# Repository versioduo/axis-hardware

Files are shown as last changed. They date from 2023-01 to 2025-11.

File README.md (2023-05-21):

# axis-hardware

🧭 Orientation Sensor Controller

## Board

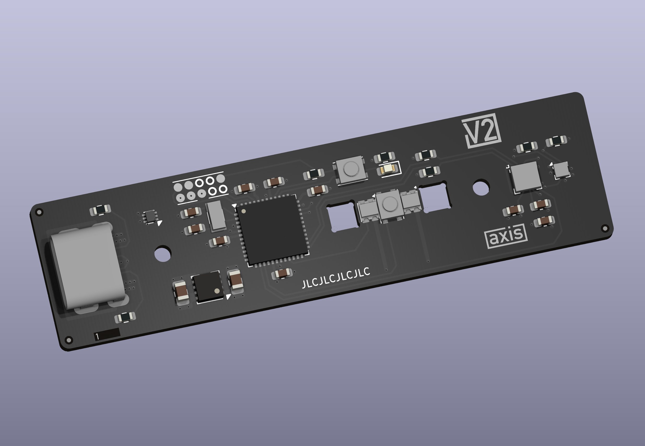
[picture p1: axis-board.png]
board


## Schematic

[PDF](axis.pdf)

## Bill Of Materials

[Interactive BOM](https://htmlpreview.github.io/?https://github.com/versioduo/axis-hardware/main/axis-bom.html)

## Software

Firmware Repository

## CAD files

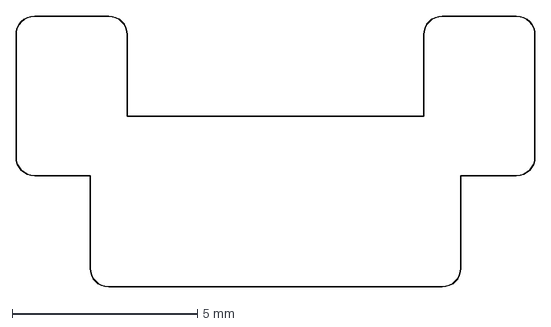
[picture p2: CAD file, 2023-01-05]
button-laser.dxf
14.0 x 7.30 mm

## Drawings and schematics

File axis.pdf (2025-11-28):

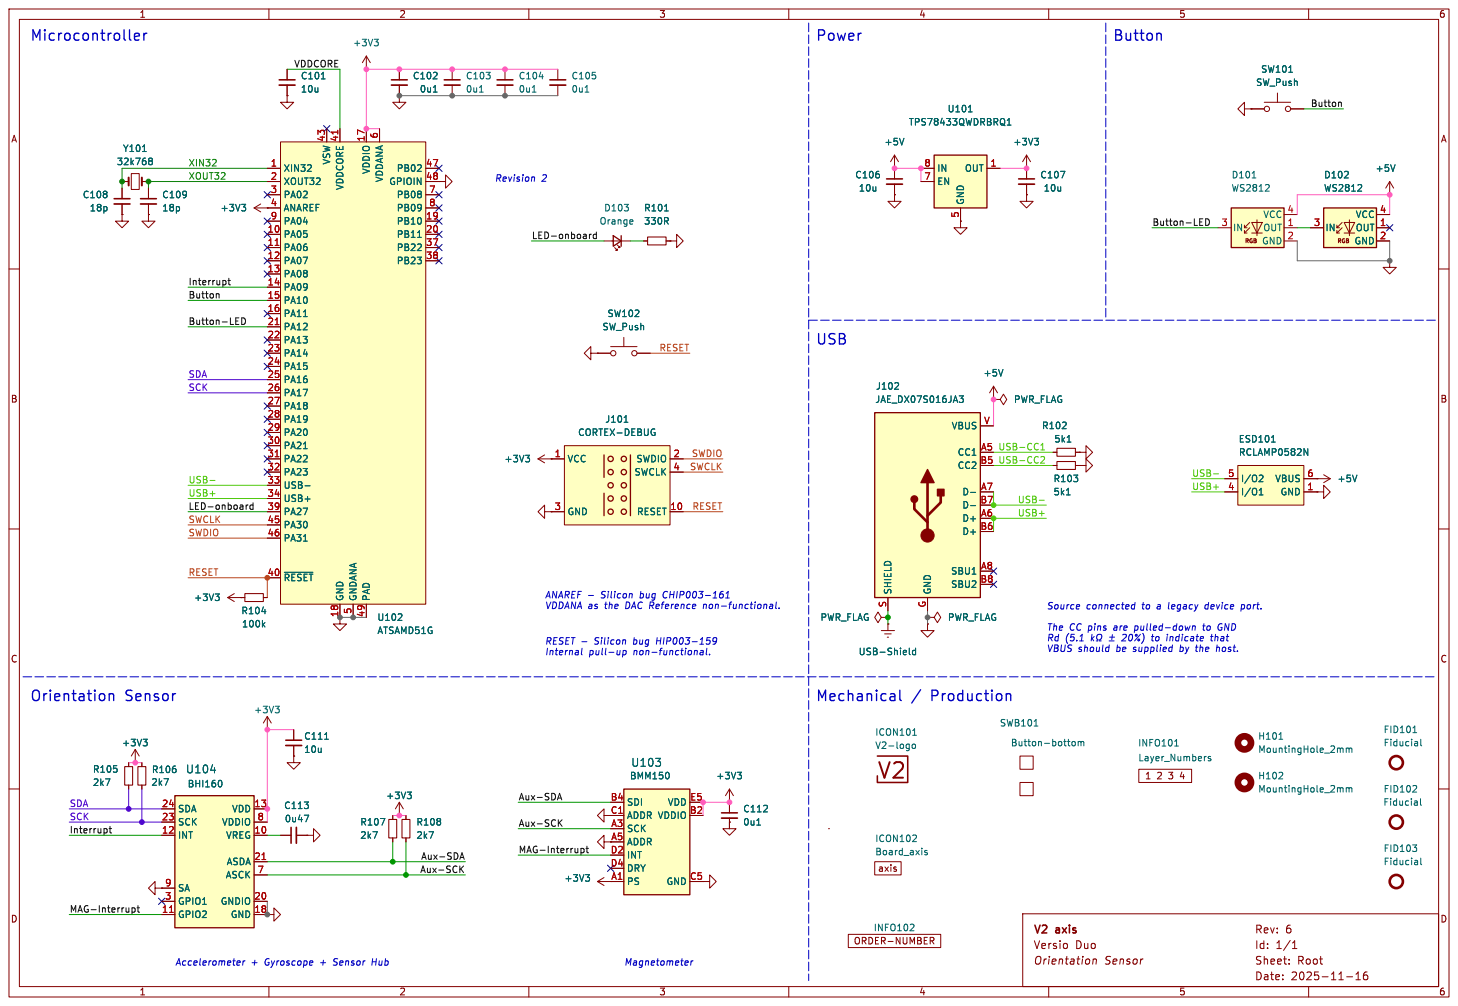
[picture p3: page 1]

þÿþÿANAREF - Silicon bug CHIP003-161 VDDANA as the DAC Reference non-functional. Microcontroller

Button SDA Orientation Sensor

LED-onboard Button-LED

USB- USB+ RESET SWCLK

Aux-SCK RESET SWCLK
SWDIO

BMM150 SDI B4 ADDR C1 SCK A3 ADDR A5

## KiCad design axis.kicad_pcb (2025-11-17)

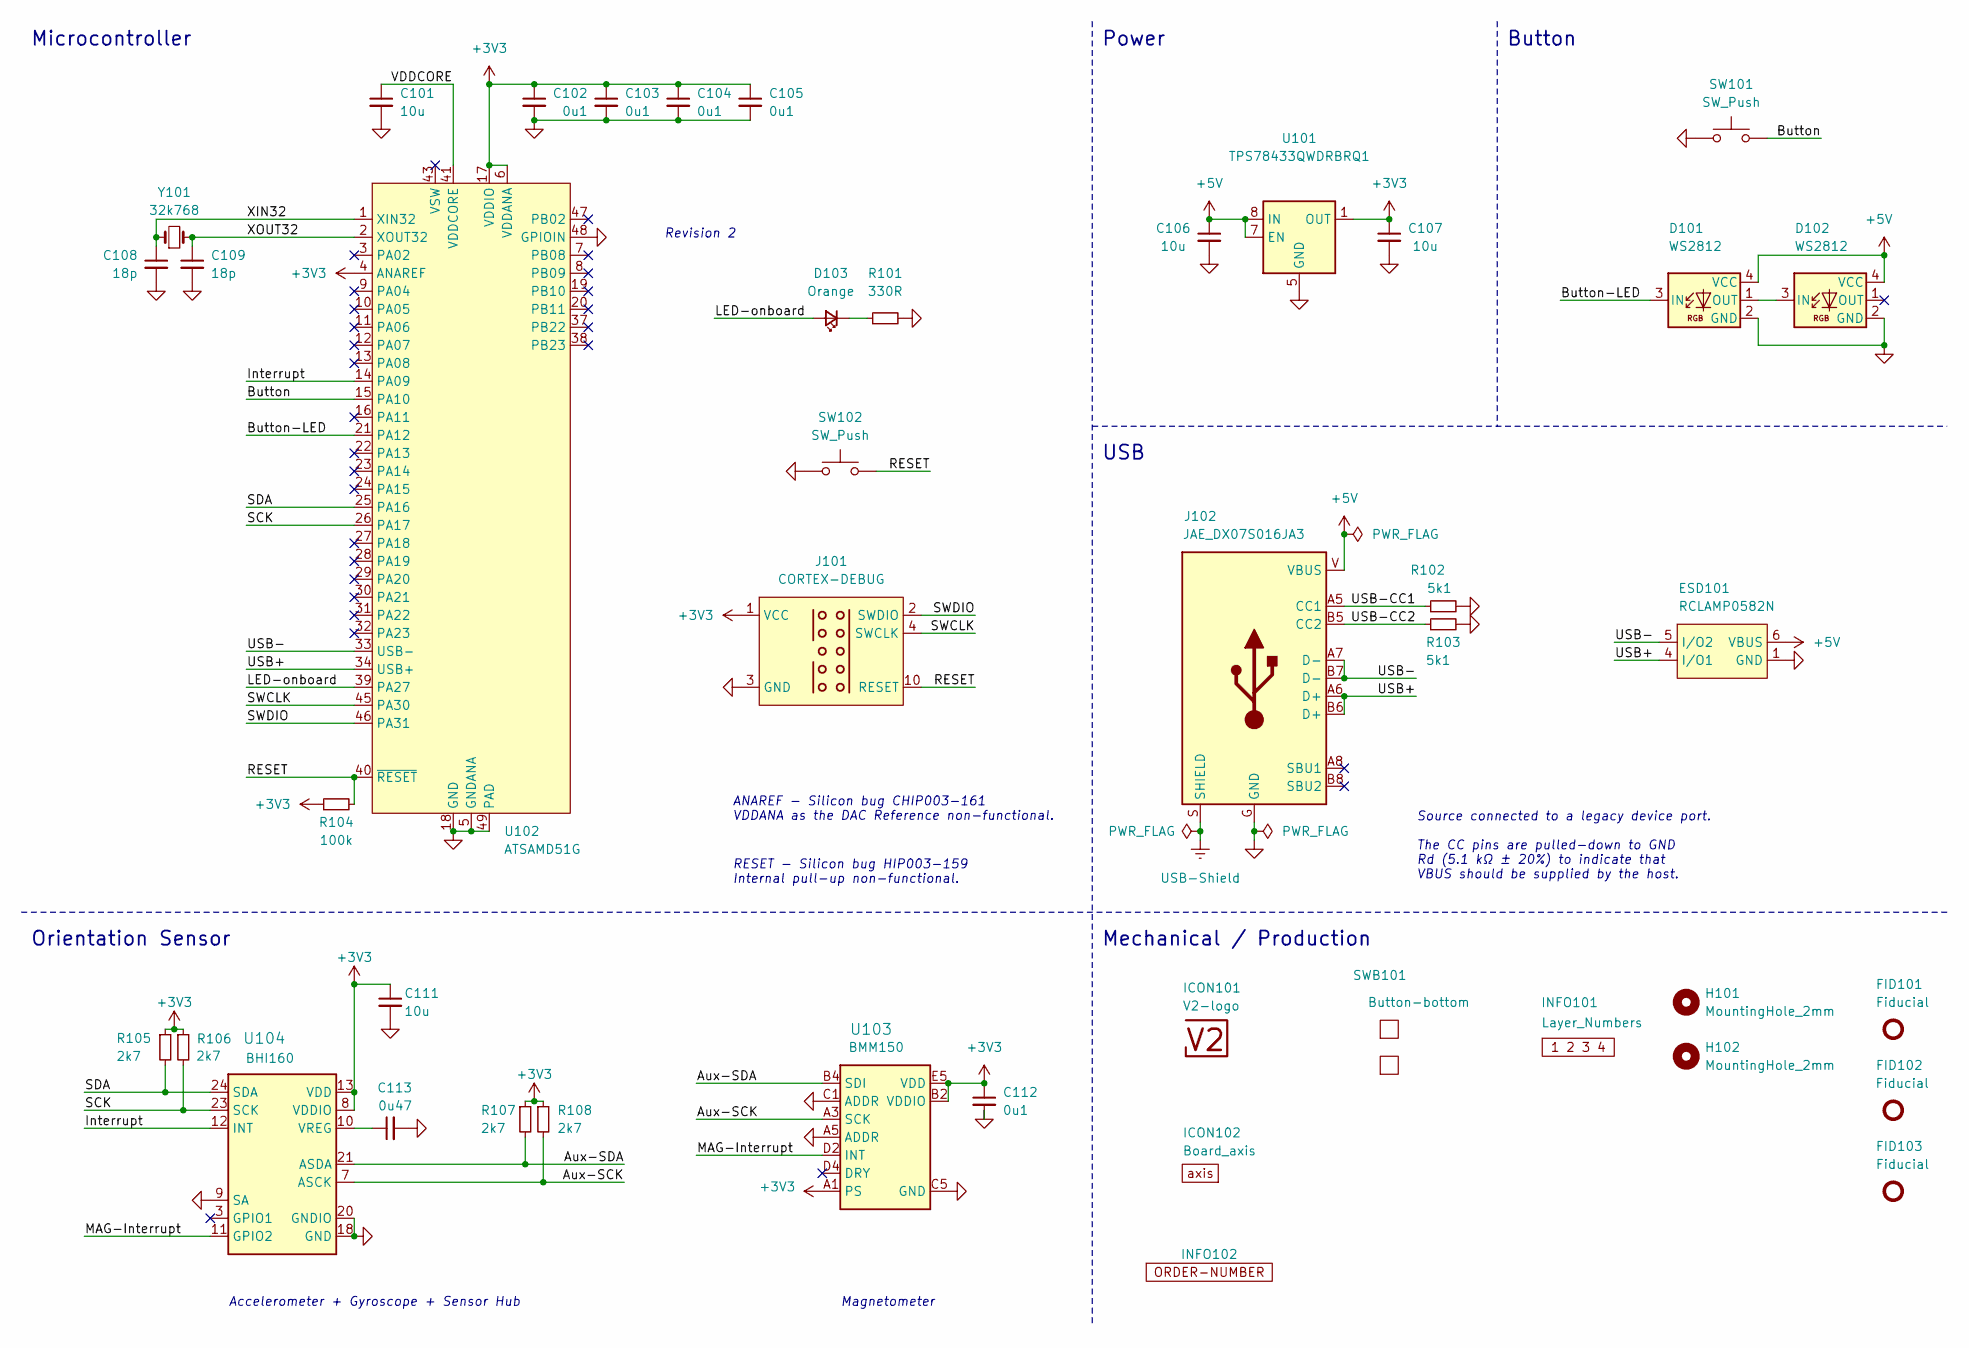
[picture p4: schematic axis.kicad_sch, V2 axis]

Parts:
C101, C111: 10u; C_0603_1608Metric
C102, C103, C104, C105, C112: 0u1; C_0603_1608Metric
C106, C107: 10u; C_0805_2012Metric
C108, C109: 18p; C_0603_1608Metric
C113: 0u47; C_0603_1608Metric
D101, D102: WS2812; WS2812-2020
D103: Orange; LED_0603_1608Metric
ESD101: RCLAMP0582N; SLP1210N6
FID101, FID102, FID103: Fiducial; Fiducial_0.5mm_Mask1mm_Paste
H101, H102: MountingHole_2mm
ICON101: V2-logo; Logo_Small
ICON102: Board_axis; Board_axis_Small
INFO101: Layer_Numbers
INFO102: ORDER-NUMBER; Order_Number
J101: CORTEX-DEBUG; Cortex_Debug_Pad
J102: JAE_DX07S016JA3
R101: 330R; R_0603_1608Metric
R102, R103: 5k1; R_0603_1608Metric
R104: 100k; R_0603_1608Metric
R105, R106, R107, R108: 2k7; R_0603_1608Metric
SW101, SW102: SW_Push; SKSG
SWB101: Button-bottom; PCB_Button-bottom
U101: TPS78433QWDRBRQ1; VSON-8-1_3x3mm_P0.65_EP1.65x2.4mm
U102: ATSAMD51G; QFN-48-1EP_7x7mm_P0.5mm_EP5.45x5.45mm_ThermalVias
U103: BMM150; WLCSP-1.56x1.56
U104: BHI160; LGA24-3x3
Y101: 32k768; Crystal_SMD_3215-2Pin_3.2x1.5mm

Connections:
+3V3: C102.1, C103.1, C104.1, C105.1, C107.1, C111.1, C112.1, J101.1 (VCC), R104.1, R105.1, R106.1, R107.1, R108.1, U101.1 (OUT), U102.4 (ANAREF), U102.6 (VDDANA), U102.17 (VDDIO), U102.36 (VDDIO), U102.44 (VDDIO), U103.A1 (PS), U103.B2 (VDDIO), U103.E5 (VDD), U104.8 (VDDIO), U104.13 (VDD)
+5V: C106.1, D101.4 (VCC), D102.4 (VCC), ESD101.6 (VBUS), J102.V (VBUS), U101.7 (EN), U101.8 (IN)
/Aux-SCK: R108.2, U103.A3 (SCK), U104.7 (ASCK)
/Aux-SDA: R107.2, U103.B4 (SDI), U104.21 (ASDA)
/Button: SW101.2, U102.15 (PA10)
/Button-LED: D101.3 (IN), U102.21 (PA12)
/Interrupt: U102.14 (PA09), U104.12 (INT)
/LED-onboard: D103.2 (A), U102.39 (PA27)
/MAG-Interrupt: U103.D2 (INT), U104.11 (GPIO2)
/RESET: J101.10 (RESET), R104.2, SW102.2, U102.40 (~RESET)
/SCK: R106.2, U102.26 (PA17), U104.23 (SCK)
/SDA: R105.2, U102.25 (PA16), U104.24 (SDA)
/SWCLK: J101.4 (SWCLK), U102.45 (PA30)
/SWDIO: J101.2 (SWDIO), U102.46 (PA31)
/USB+: ESD101.4 (I/O1), J102.A6 (D+), J102.B6 (D+), U102.34 (USB+)
/USB-: ESD101.5 (I/O2), J102.A7 (D-), J102.B7 (D-), U102.33 (USB-)
/USB-CC1: J102.A5 (CC1), R102.1
/USB-CC2: J102.B5 (CC2), R103.1
/VDDCORE: C101.1, U102.41 (VDDCORE)
/XIN32: C108.1, U102.1 (XIN32), Y101.1
/XOUT32: C109.1, U102.2 (XOUT32), Y101.2
GND: C101.2, C102.2, C103.2, C104.2, C105.2, C106.2, C107.2, C108.2, C109.2, C111.2, C112.2, C113.2, D101.2 (GND), D102.2 (GND), ESD101.1 (GND), J101.3 (GND), J101.5 (GND), J102.G (GND), R101.2, R102.2, R103.2, SW101.1, SW102.1, U101.5 (GND), U101.9 (GND), U102.5 (GNDANA), U102.18 (GND), U102.35 (GND), U102.42 (GND), U102.48 (GPIOIN), U102.49 (PAD), U103.A5 (ADDR), U103.C1 (ADDR), U103.C5 (GND), U103.E1 (GND), U103.E3 (GND), U104.9 (SA), U104.18 (GND), U104.20 (GNDIO)
unnamed: D101.1 (OUT), D102.3 (IN)
unnamed: D103.1 (K), R101.1
unnamed: C113.1, U104.10 (VREG)
USB-Shield: J102.S (SHIELD)

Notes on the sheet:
 ANAREF - Silicon bug CHIP003-161 VDDANA as the DAC Reference non-functional.
RESET -  Silicon bug HIP003-159 Internal pull-up non-functional.
 Source connected to a legacy device port. The CC pins are pulled-down to GND Rd (5.1 kΩ ± 20%) to indicate that VBUS should be supplied by the host.
Button
Revision 2
Mechanical / Production
Magnetometer
Power
Accelerometer + Gyroscope + Sensor Hub
Microcontroller
USB
Orientation Sensor

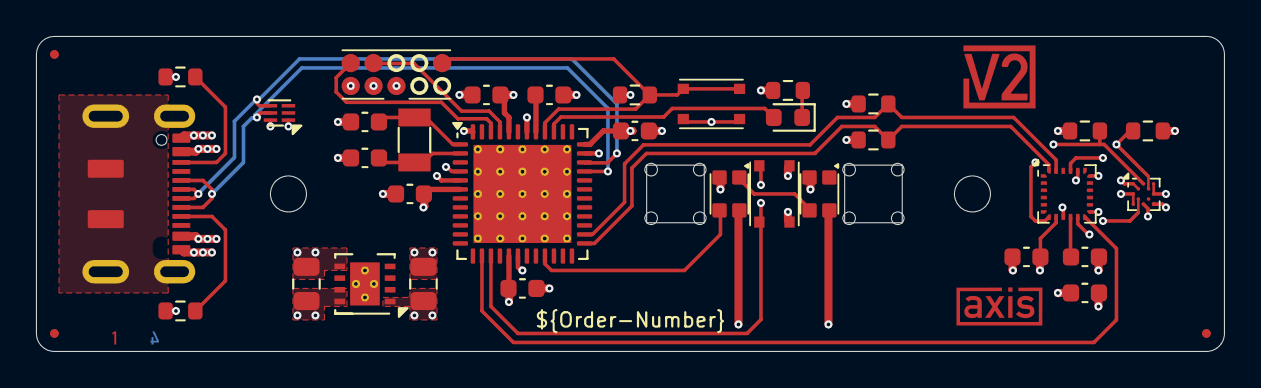
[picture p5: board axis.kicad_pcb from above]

Board: 4 copper layers, 66.0 x 17.5 mm, 43 parts (0 on the bottom side), 25 nets.

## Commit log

2023-05-21 Update to KiCat 7.0
    [axis-cover.kicad_pcb, axis-cover.kicad_sch, axis.kicad_pcb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]
2024-03-28 Update to Kicad 8
    [axis-cover.kicad_pcb, axis-cover.kicad_sch, axis.kicad_pcb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]
2025-10-26 Replace LDO
    [axis.kicad_pcb, axis.kicad_sch]
2025-10-30 GND label
    [axis.kicad_pcb, axis.kicad_sch]
2025-11-02 Replace standoffs
    [axis-cover.kicad_pcb, axis.kicad_pcb, axis.kicad_sch]
2025-11-15 Add front + back
    [back.kicad_pcb, back.kicad_sch, front.kicad_pcb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]
2025-11-16 Change capacitors
    [axis.kicad_pcb, axis.kicad_sch]
